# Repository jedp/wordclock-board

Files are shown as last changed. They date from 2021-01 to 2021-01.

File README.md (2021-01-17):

## Notes

### STM32F04

Programmed via ST-Link (CLK, GND, DIO, NRST). Easy peasy!

External low-speed crystal oscillator (32.768kHz) enables real-time clock
module to function on VBAT when VDD is disconnected.

### MAX7129

Imagine the 64 LEDs are 8 7-segment LEDs.

Pin 1 DATA: Data loaded on CLK's rising edge.

Pin 12 NCS: Data is loaded into the shift register when this is low.

Pin 13 CLK.

Pins 2, 3, 5, 6, 7, 8, 10, and 11 (the DIG pins) are pulled high when
switched off.

Pins 14, 15, 16, 17, 20, 21, 22, and 22 (the SEG and DP pins) are pulled low when
switched off.

Note that peak current is set with an external resistor on pin 18 (R1). The
datasheet has a section on how to select the correct resistor value. Note that
you need to do this whether or not you use the `intensity` configuration,
because the MAX7219 will power up into a test mode with all LEDs blazing
*before* your configurations takes effect. You could probably burn out your
nice display by accident this way. So you can tweak the 10k resistor on R1, but
don't jump it.

### Other assorted components

MCP1802: LDO voltage regulator (5V to 3V3).

USBLC6: ESD protection on the USB interface.

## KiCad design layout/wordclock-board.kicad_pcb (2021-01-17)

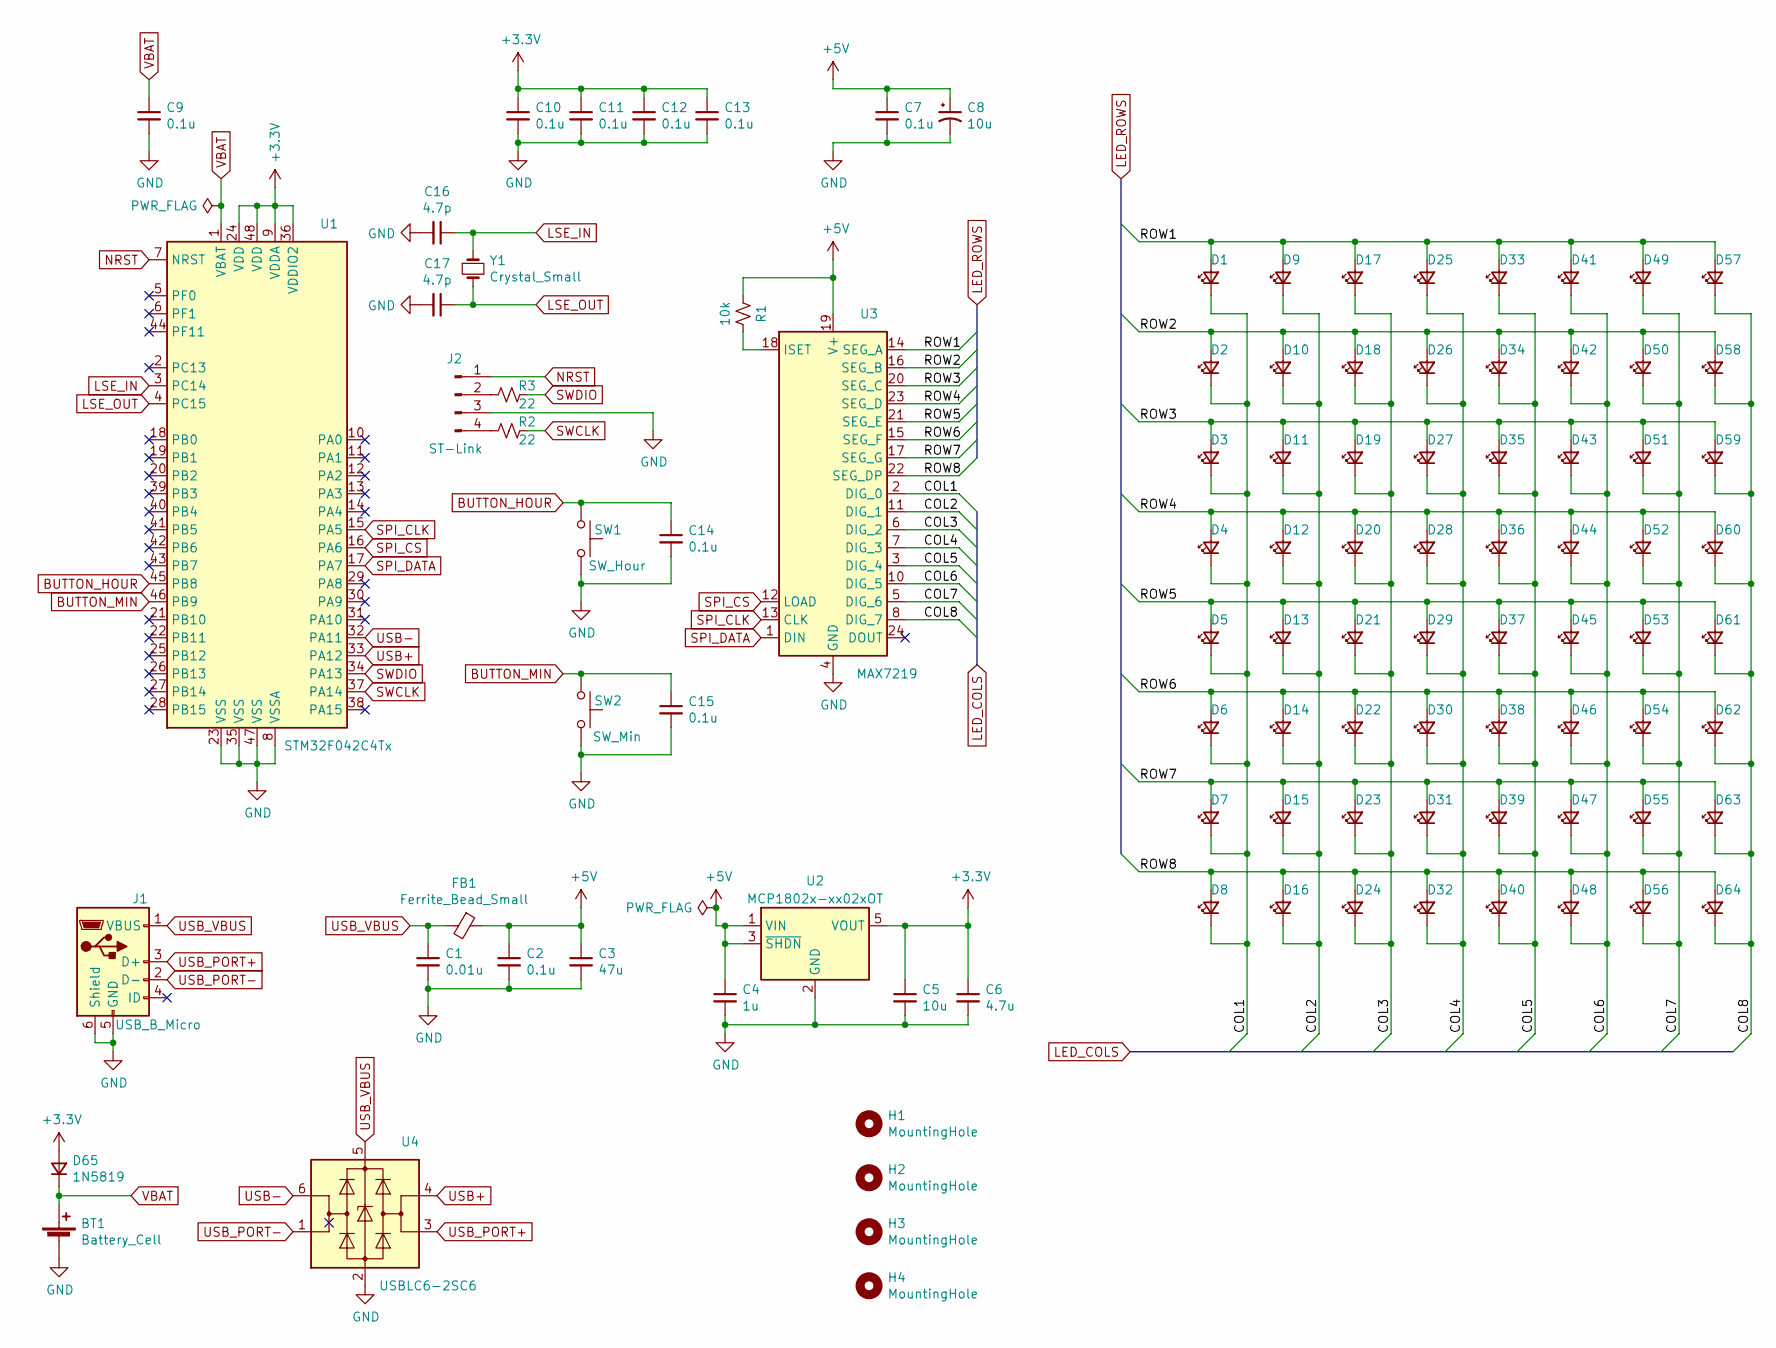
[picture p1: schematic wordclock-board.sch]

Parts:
BT1: Battery_Cell; BatteryHolder_Seiko_MS621F
C1: 0.01u; C_0603_1608Metric
C2, C7, C9, C10, C11, C12, C13: 0.1u; C_0603_1608Metric
C3: 47u; C_0805_2012Metric
C4: 1u; C_0603_1608Metric
C5: 10u; C_0805_2012Metric
C6: 4.7u; C_0805_2012Metric
C8: 10u; CP_Elec_5x4.5
C14, C15: 0.1u; C_0805_2012Metric
C16, C17: 4.7p; C_0603_1608Metric
D1, D2, D3, D4, D5, D6, D7, D8, D9, D10, D11, D12, D13, D14, D15, D16, D17, D18, D19, D20, D21, D22, D23, D24, D25, D26, D27, D28, D29, D30, D31, D32, D33, D34, D35, D36, D37, D38, D39, D40, D41, D42, D43, D44, D45, D46, D47, D48, D49, D50, D51, D52, D53, D54, D55, D56, D57, D58, D59, D60, D61, D62, D63, D64: LED_Small; LED_0603_1608Metric
D65: 1N5819; D_0805_2012Metric
FB1: Ferrite_Bead_Small; L_0805_2012Metric
H1, H2, H3, H4: MountingHole; MountingHole_3.2mm_M3
J1: USB_B_Micro; USB_Micro-B_Molex-105133-0001
J2: ST-Link; PinHeader_1x04_P2.54mm_Vertical
R1: 10k; R_0603_1608Metric
R2, R3: 22; R_0603_1608Metric
SW1: SW_Hour; SW_Tactile_SPST_Angled_PTS645Vx83-2LFS
SW2: SW_Min; SW_Tactile_SPST_Angled_PTS645Vx83-2LFS
U1: STM32F042C4Tx; LQFP-48_7x7mm_P0.5mm
U2: MCP1802x-xx02xOT; SOT-23-5
U3: MAX7219; SOIC-24W_7.5x15.4mm_P1.27mm
U4: USBLC6-2SC6; SOT-23-6
Y1: Crystal_Small; Crystal_SMD_MicroCrystal_CC5V-T1A-2Pin_4.1x1.5mm_HandSolder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

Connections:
+3V3: C5.1, C6.1, C10.1, C11.1, C12.1, C13.1, D65.2 (A), U1.9 (VDDA), U1.24 (VDD), U1.36 (VDDIO2), U1.48 (VDD), U2.5 (VOUT)
+5V: C2.1, C3.1, C4.1, C7.1, C8.1, FB1.1, R1.2, U2.1 (VIN), U2.3 (~SHDN), U3.19 (V+)
/COL1: D1.1 (K), D2.1 (K), D3.1 (K), D4.1 (K), D5.1 (K), D6.1 (K), D7.1 (K), D8.1 (K), U3.2 (DIG_0)
/COL2: D9.1 (K), D10.1 (K), D11.1 (K), D12.1 (K), D13.1 (K), D14.1 (K), D15.1 (K), D16.1 (K), U3.11 (DIG_1)
/COL3: D17.1 (K), D18.1 (K), D19.1 (K), D20.1 (K), D21.1 (K), D22.1 (K), D23.1 (K), D24.1 (K), U3.6 (DIG_2)
/COL4: D25.1 (K), D26.1 (K), D27.1 (K), D28.1 (K), D29.1 (K), D30.1 (K), D31.1 (K), D32.1 (K), U3.7 (DIG_3)
/COL5: D33.1 (K), D34.1 (K), D35.1 (K), D36.1 (K), D37.1 (K), D38.1 (K), D39.1 (K), D40.1 (K), U3.3 (DIG_4)
/COL6: D41.1 (K), D42.1 (K), D43.1 (K), D44.1 (K), D45.1 (K), D46.1 (K), D47.1 (K), D48.1 (K), U3.10 (DIG_5)
/COL7: D49.1 (K), D50.1 (K), D51.1 (K), D52.1 (K), D53.1 (K), D54.1 (K), D55.1 (K), D56.1 (K), U3.5 (DIG_6)
/COL8: D57.1 (K), D58.1 (K), D59.1 (K), D60.1 (K), D61.1 (K), D62.1 (K), D63.1 (K), D64.1 (K), U3.8 (DIG_7)
/ROW1: D1.2 (A), D9.2 (A), D17.2 (A), D25.2 (A), D33.2 (A), D41.2 (A), D49.2 (A), D57.2 (A), U3.14 (SEG_A)
/ROW2: D2.2 (A), D10.2 (A), D18.2 (A), D26.2 (A), D34.2 (A), D42.2 (A), D50.2 (A), D58.2 (A), U3.16 (SEG_B)
/ROW3: D3.2 (A), D11.2 (A), D19.2 (A), D27.2 (A), D35.2 (A), D43.2 (A), D51.2 (A), D59.2 (A), U3.20 (SEG_C)
/ROW4: D4.2 (A), D12.2 (A), D20.2 (A), D28.2 (A), D36.2 (A), D44.2 (A), D52.2 (A), D60.2 (A), U3.23 (SEG_D)
/ROW5: D5.2 (A), D13.2 (A), D21.2 (A), D29.2 (A), D37.2 (A), D45.2 (A), D53.2 (A), D61.2 (A), U3.21 (SEG_E)
/ROW6: D6.2 (A), D14.2 (A), D22.2 (A), D30.2 (A), D38.2 (A), D46.2 (A), D54.2 (A), D62.2 (A), U3.15 (SEG_F)
/ROW7: D7.2 (A), D15.2 (A), D23.2 (A), D31.2 (A), D39.2 (A), D47.2 (A), D55.2 (A), D63.2 (A), U3.17 (SEG_G)
/ROW8: D8.2 (A), D16.2 (A), D24.2 (A), D32.2 (A), D40.2 (A), D48.2 (A), D56.2 (A), D64.2 (A), U3.22 (SEG_DP)
BUTTON_HOUR: C14.1, SW1.1, U1.45 (PB8)
BUTTON_MIN: C15.1, SW2.1, U1.46 (PB9)
GND: BT1.2 (-), C1.2, C2.2, C3.2, C4.2, C5.2, C6.2, C7.2, C8.2, C9.2, C10.2, C11.2, C12.2, C13.2, C14.2, C15.2, C16.2, C17.2, J1.5 (GND), J1.6 (Shield), J2.3, SW1.2, SW2.2, U1.8 (VSSA), U1.23 (VSS), U1.35 (VSS), U1.47 (VSS), U2.2 (GND), U3.4 (GND), U3.9 (GND), U4.2 (GND)
LSE_IN: C16.1, U1.3 (PC14), Y1.1
LSE_OUT: C17.1, U1.4 (PC15), Y1.2
NRST: J2.1, U1.7 (NRST)
unnamed: J2.2, R3.2
unnamed: J2.4, R2.2
unnamed: R1.1, U3.18 (ISET)
SPI_CLK: U1.15 (PA5), U3.13 (CLK)
SPI_CS: U1.16 (PA6), U3.12 (LOAD)
SPI_DATA: U1.17 (PA7), U3.1 (DIN)
SWCLK: R2.1, U1.37 (PA14)
SWDIO: R3.1, U1.34 (PA13)
USB+: U1.33 (PA12), U4.4 (I/O2)
USB-: U1.32 (PA11), U4.6 (I/O1)
USB_PORT+: J1.3 (D+), U4.3 (I/O2)
USB_PORT-: J1.2 (D-), U4.1 (I/O1)
USB_VBUS: C1.1, FB1.2, J1.1 (VBUS), U4.5 (VBUS)
VBAT: BT1.1 (+), C9.1, D65.1 (K), U1.1 (VBAT)

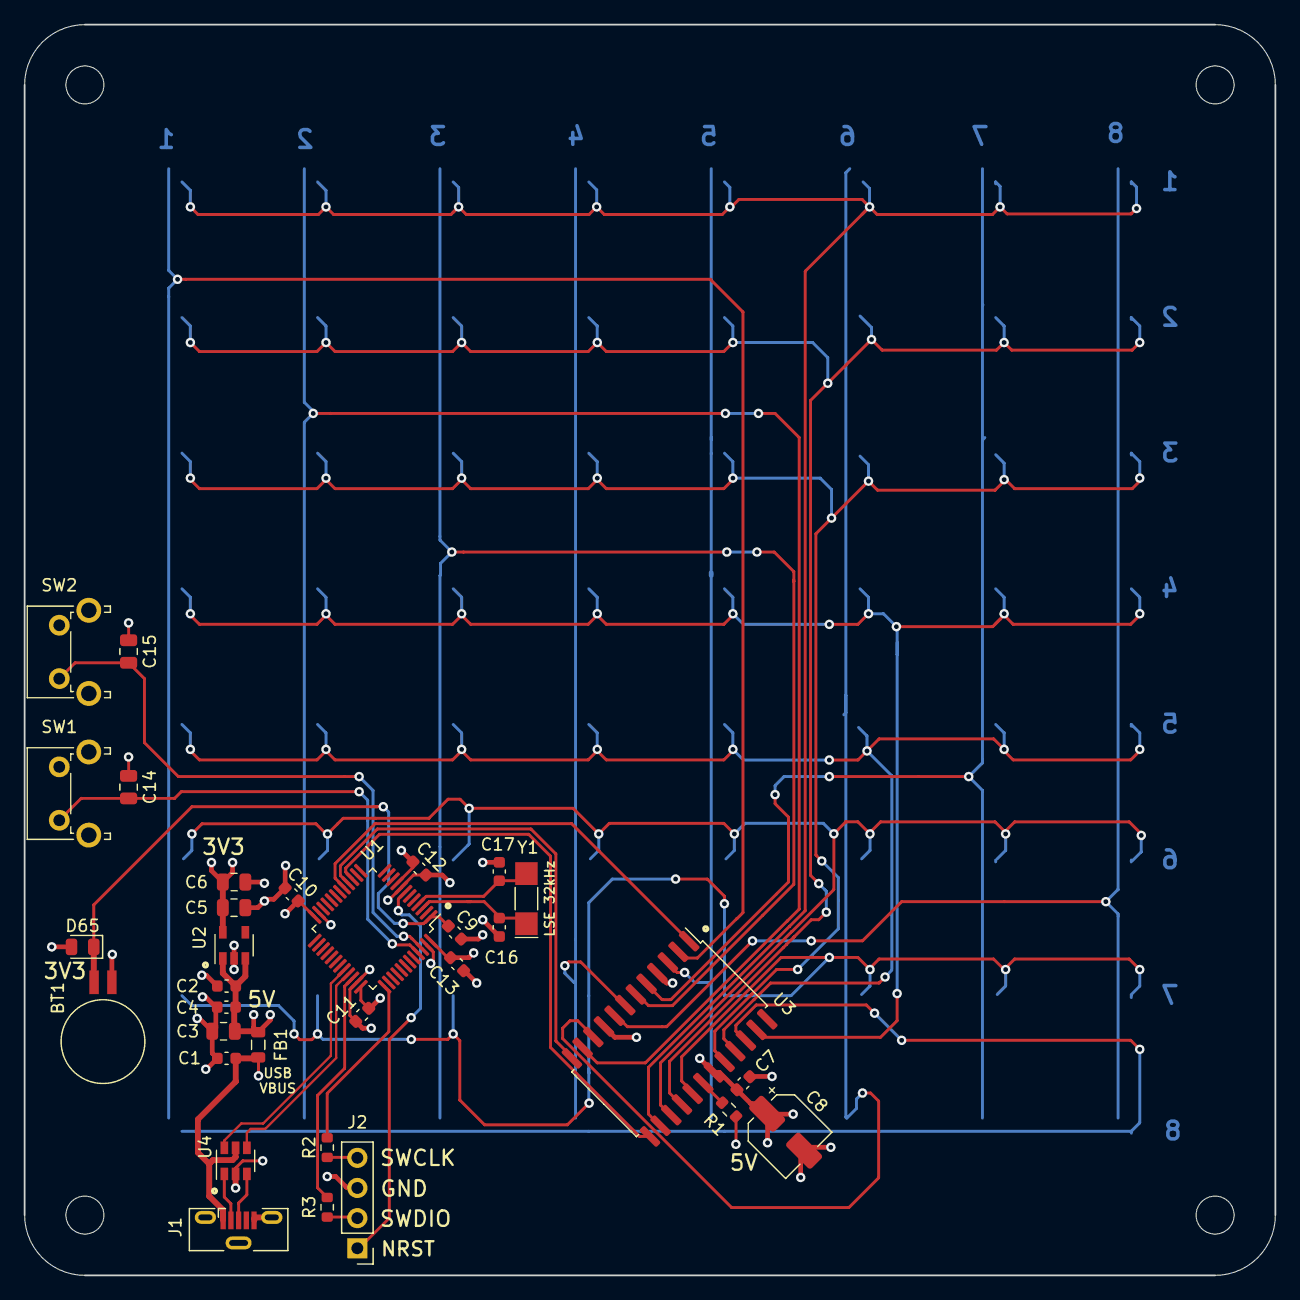
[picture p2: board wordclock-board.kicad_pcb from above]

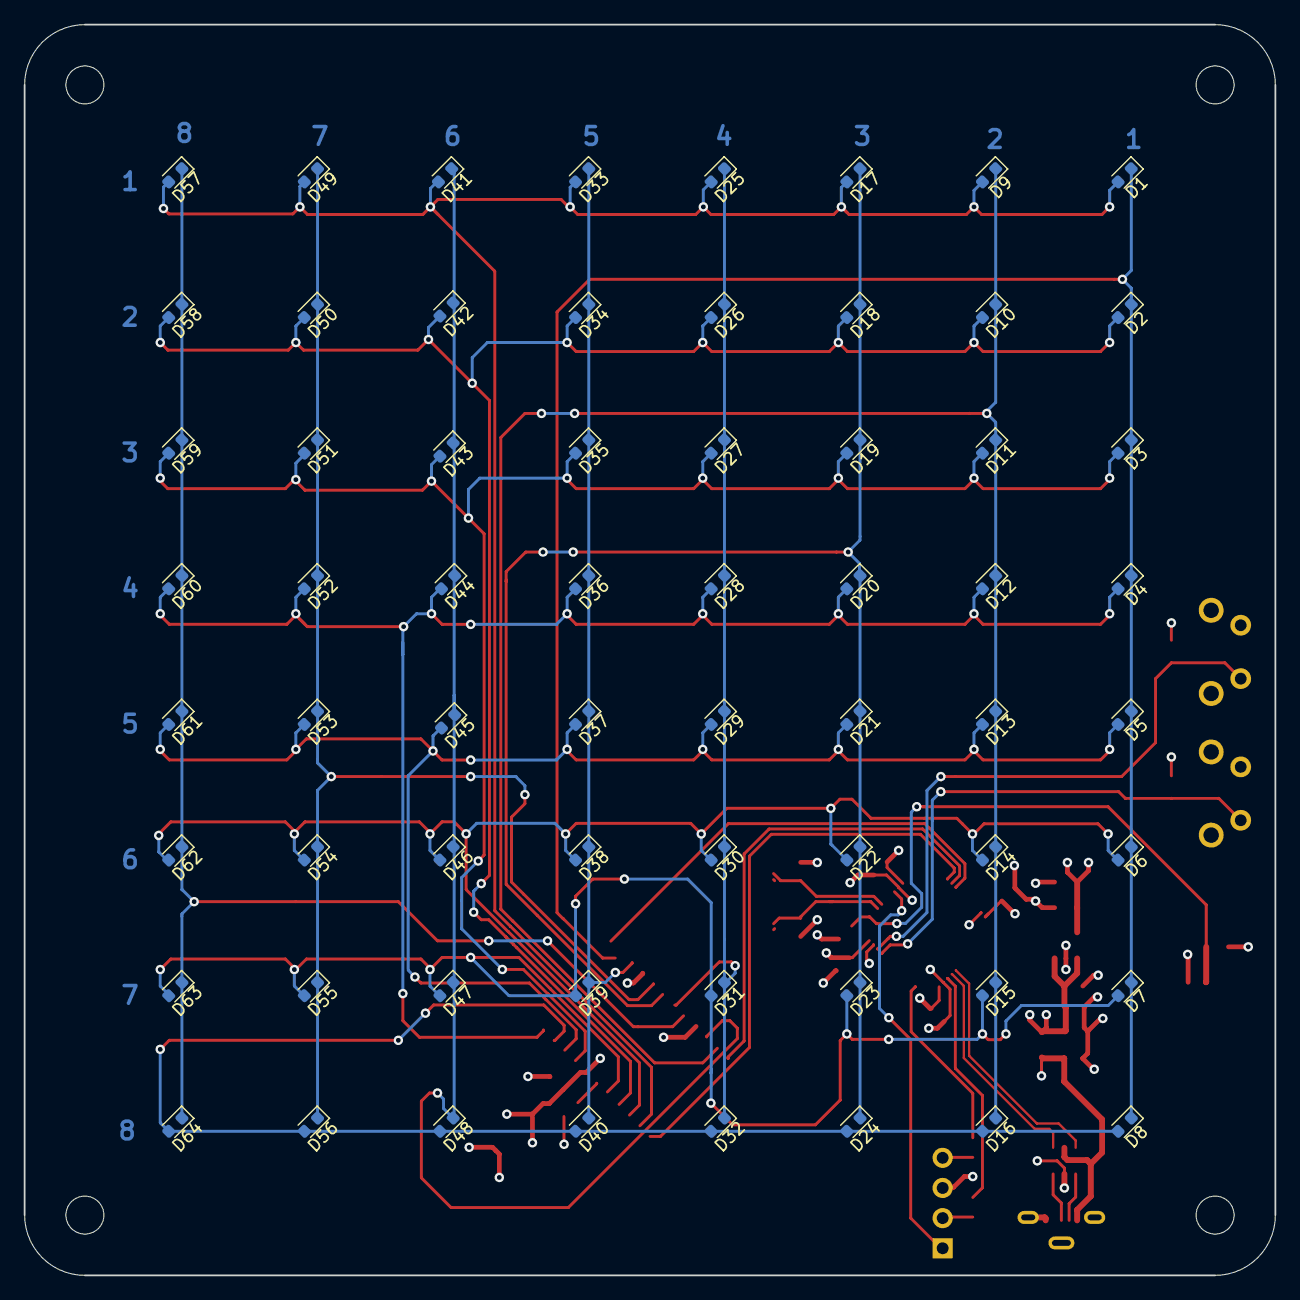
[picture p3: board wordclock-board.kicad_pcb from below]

Board: 4 copper layers, 105.4 x 105.4 mm, 100 parts (64 on the bottom side), 38 nets.

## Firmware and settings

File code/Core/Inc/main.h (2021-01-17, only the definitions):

#define SPI1_CS_Pin GPIO_PIN_6
#define SPI1_CS_GPIO_Port GPIOA
#define INCR_HOUR_Pin GPIO_PIN_8
#define INCR_HOUR_GPIO_Port GPIOB
#define INCR_MIN_Pin GPIO_PIN_9
#define INCR_MIN_GPIO_Port GPIOB

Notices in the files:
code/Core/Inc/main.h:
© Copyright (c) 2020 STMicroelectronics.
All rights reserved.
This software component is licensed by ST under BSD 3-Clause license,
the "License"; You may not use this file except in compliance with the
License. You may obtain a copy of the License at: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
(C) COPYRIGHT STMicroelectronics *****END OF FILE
